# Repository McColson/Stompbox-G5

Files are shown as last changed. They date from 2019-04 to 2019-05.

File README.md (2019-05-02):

# Stompbox-G5
Guitar preamp stompbox

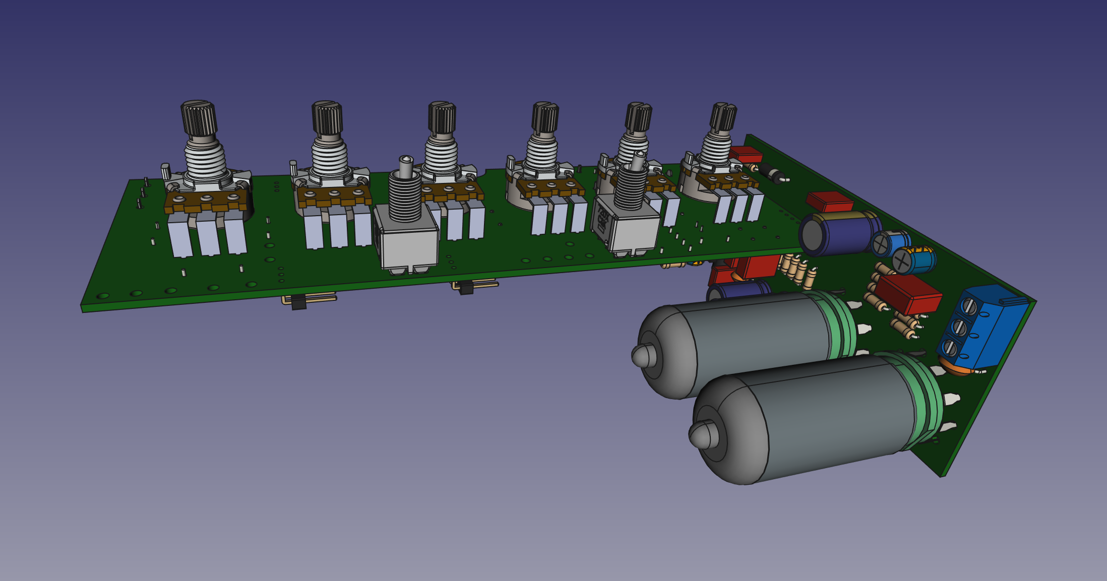
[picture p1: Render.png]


<br />Ce(tte) œuvre est mise à disposition selon les termes de la <a rel="license" href="http://creativecommons.org/licenses/by-nc-sa/4.0/">Licence Creative Commons Attribution - Pas d’Utilisation Commerciale - Partage dans les Mêmes Conditions 4.0 International</a>.

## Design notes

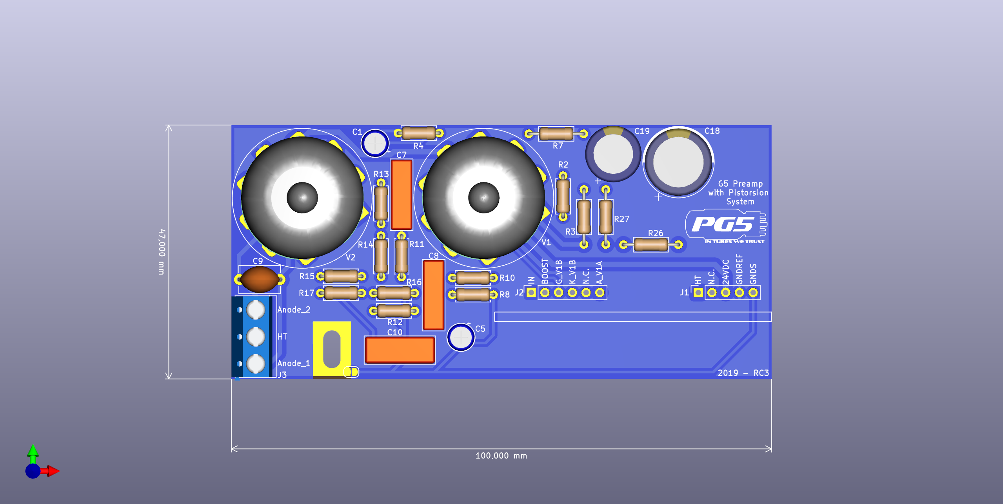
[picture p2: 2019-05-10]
G5_preamp/RC3/PCB_tube/pcb_tube.png

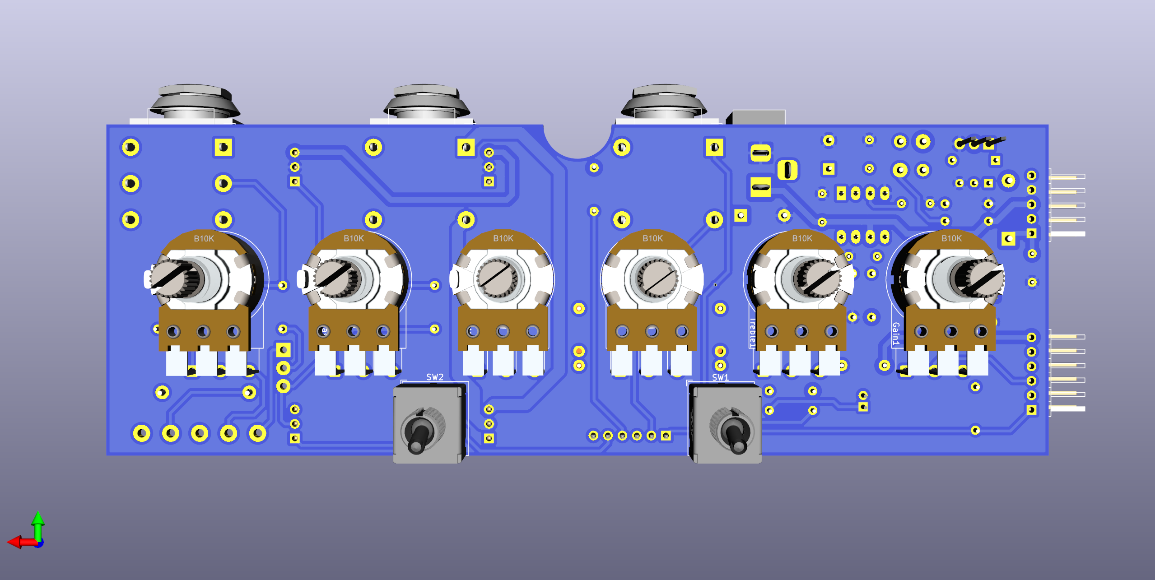
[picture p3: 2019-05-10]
G5_preamp/RC3/PCB_main/pcb_main_2.png

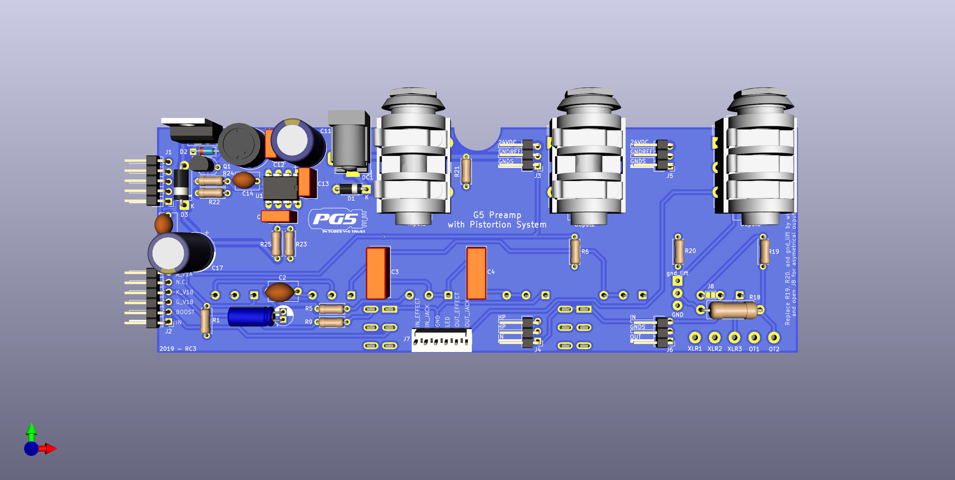
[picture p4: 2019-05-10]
G5_preamp/RC3/PCB_main/pcb_main_1.png

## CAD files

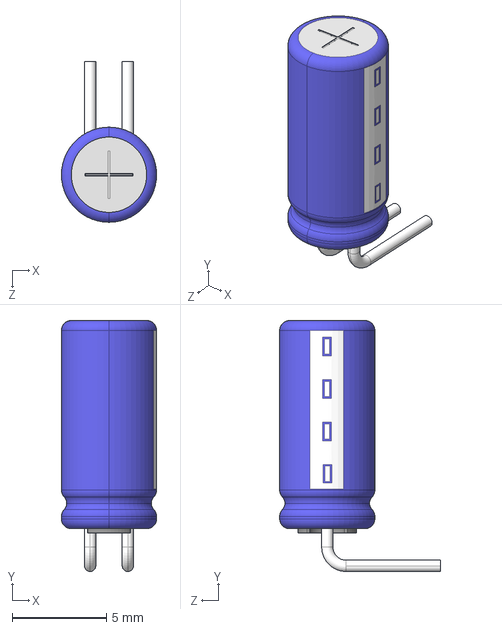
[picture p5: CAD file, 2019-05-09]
G5_preamp/RC3/PCB_main/3D/User Library-Cap electro 5x11x2mm RA.step
5.05 x 13.3 x 8.53 mm

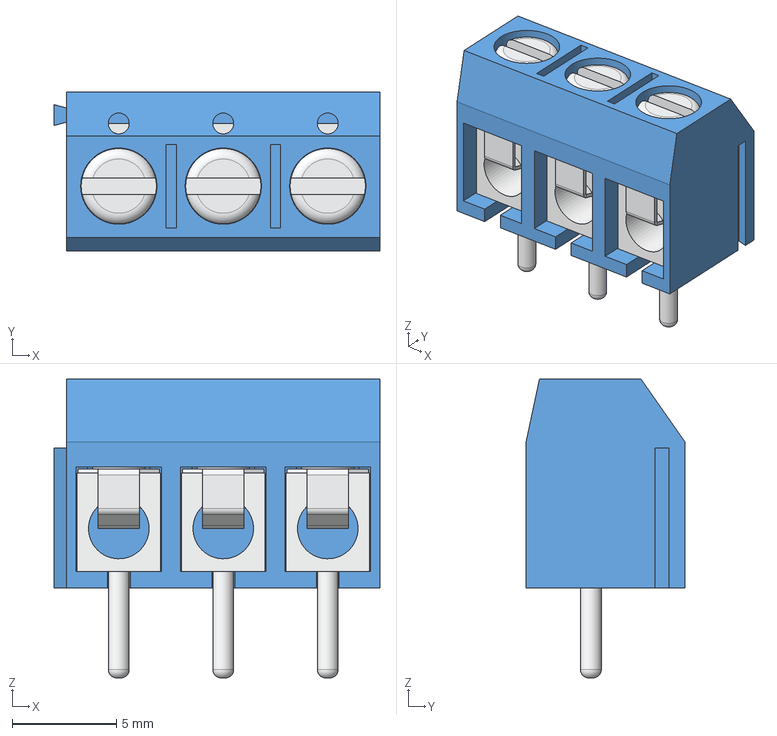
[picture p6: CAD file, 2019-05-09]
G5_preamp/RC3/PCB_tube/3D/DG301-5.0-03.stp
15.6 x 7.60 x 14.3 mm

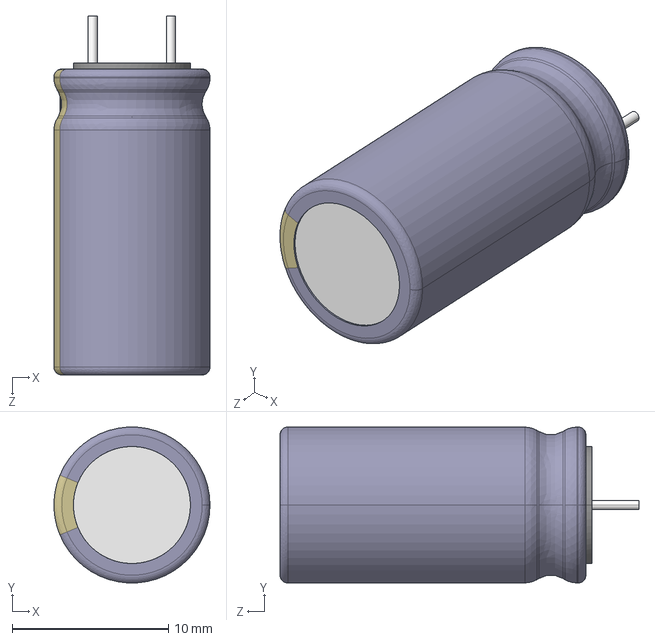
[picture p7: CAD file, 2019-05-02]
G5_preamp/RC3/PCB_main/3D/User Library-CapAluRadial_D100H200P50.step
9.99 x 9.99 x 23.0 mm

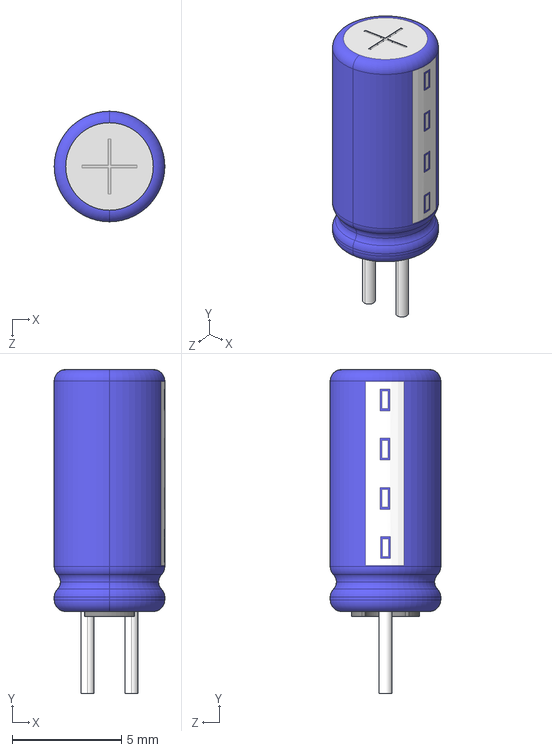
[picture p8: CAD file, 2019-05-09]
G5_preamp/RC3/PCB_tube/3D/User Library-Cap electro 5x11x2mm.step
5.05 x 14.8 x 5.05 mm

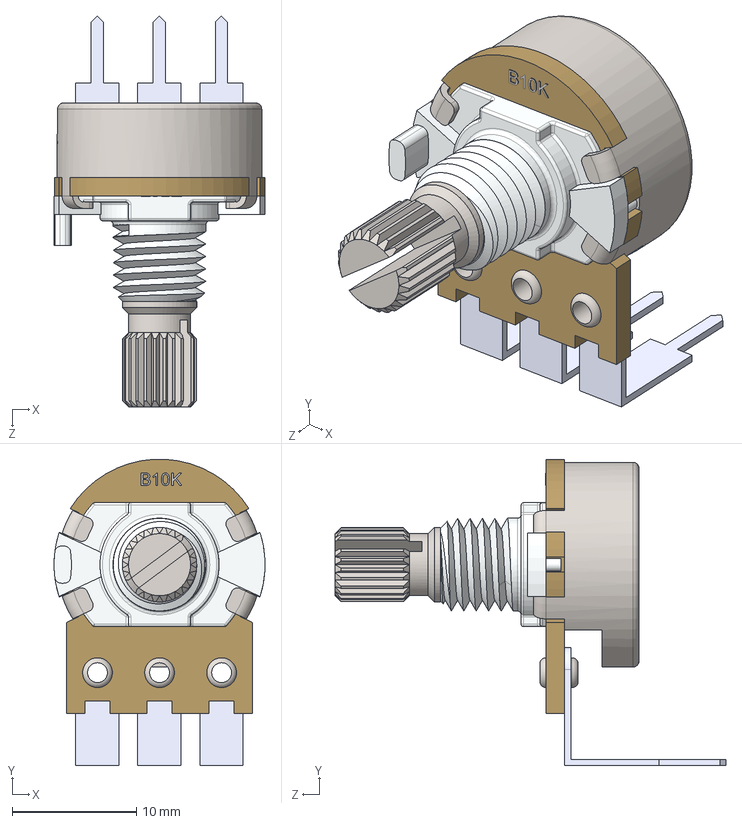
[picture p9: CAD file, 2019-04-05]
G5_preamp/RC3/PCB_main/3D/alpha_16mm_right angled.STEP
17.0 x 24.7 x 31.5 mm
P160NK___ _________
pin right angle x 3
P160NK

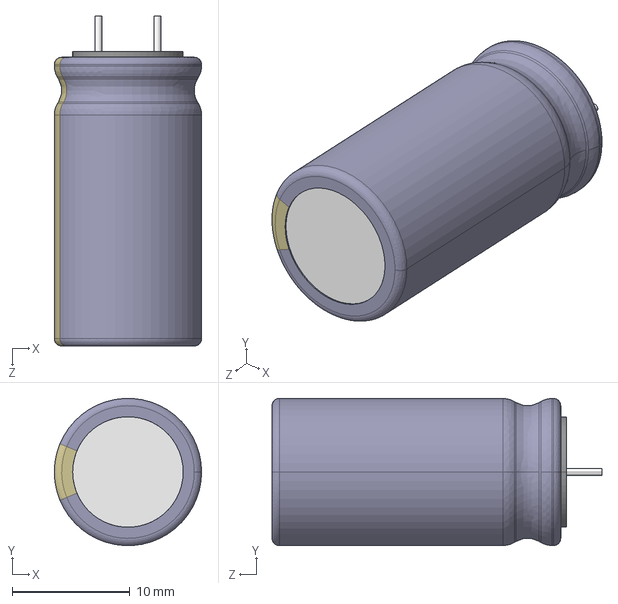
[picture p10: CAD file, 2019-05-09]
G5_preamp/RC3/PCB_tube/3D/User Library-CapAluRadial_D125H250P50.step
12.5 x 12.5 x 28.0 mm

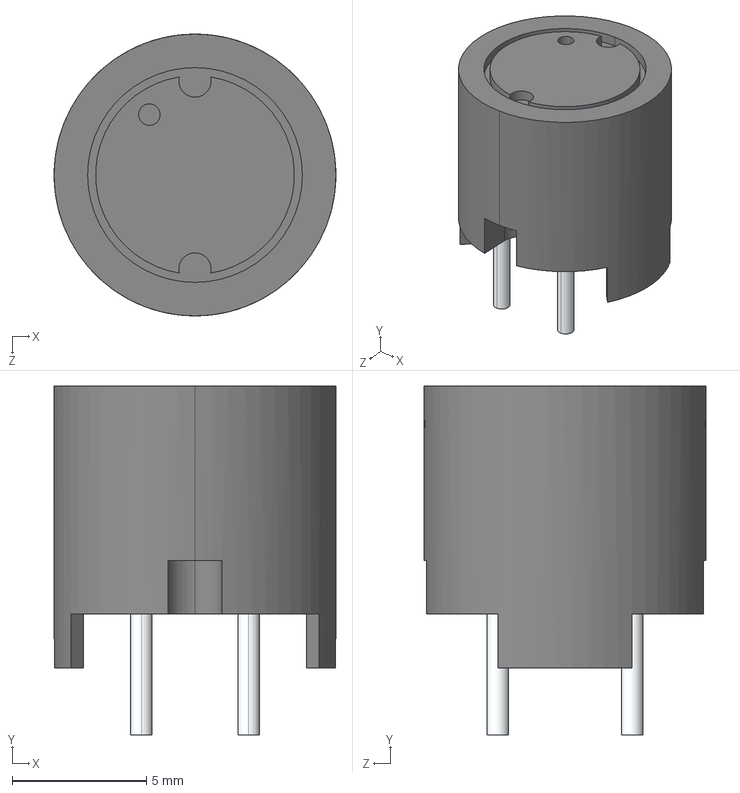
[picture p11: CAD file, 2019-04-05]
G5_preamp/RC3/PCB_main/3D/Murata_1200RS.step
10.5 x 13.0 x 10.5 mm

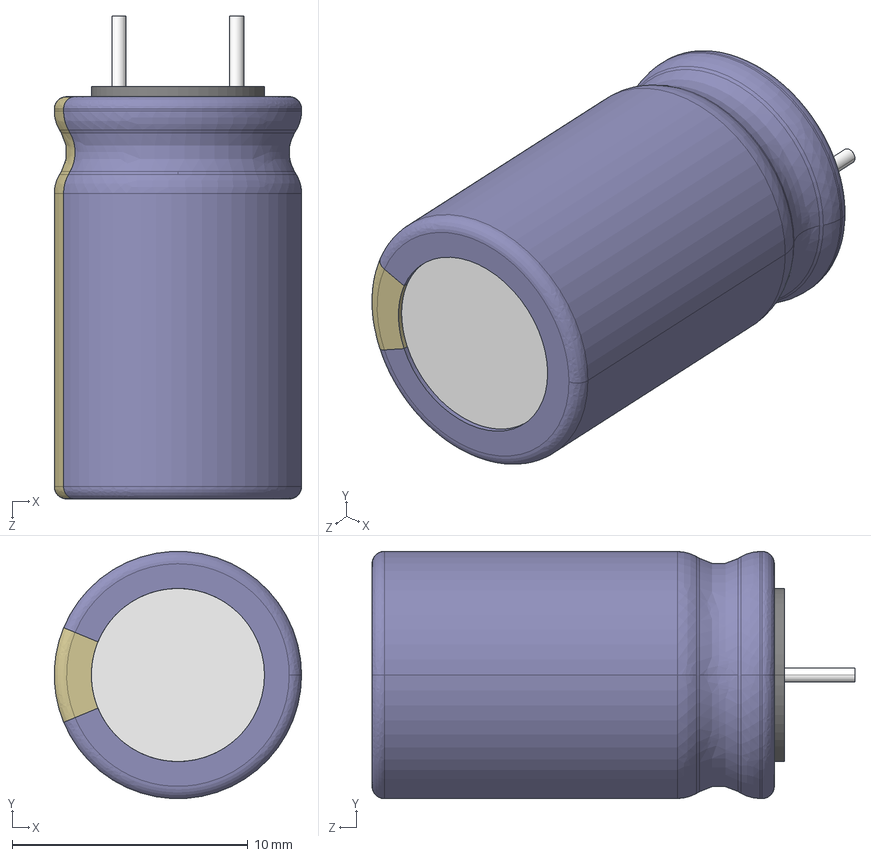
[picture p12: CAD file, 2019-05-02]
G5_preamp/RC3/PCB_tube/3D/User Library-CapAluRadial_D100H160.STEP
10.5 x 10.5 x 20.5 mm
User Library-CapAluRadial_D100H160_rubber_pad
User Library-CapAluRadial_D100H160_can
User Library-CapAluRadial_D100H160_shell_and_minus
User Library-CapAluRadial_D100H160_shell_and_minus_2
User Library-CapAluRadial_D100H160_lead x 2

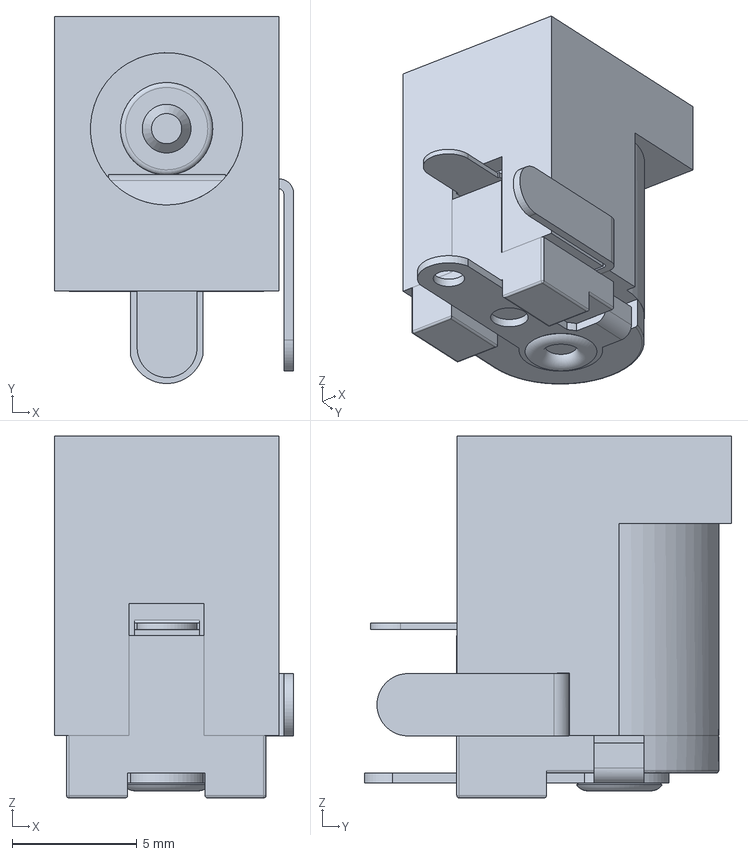
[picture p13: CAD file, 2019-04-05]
G5_preamp/RC3/PCB_main/3D/Lumberg_NEB_21_R.stp
9.59 x 14.7 x 14.5 mm

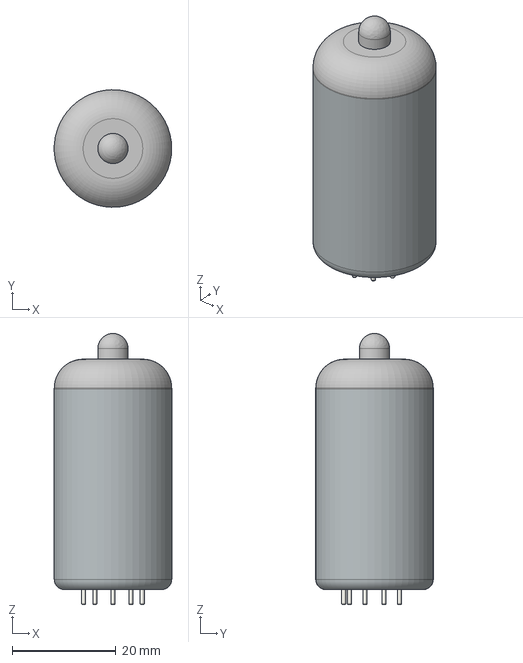
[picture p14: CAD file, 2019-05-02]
G5_preamp/RC3/PCB_tube/3D/Valve_Tube_Noval-B9A.step
22.7 x 22.7 x 52.3 mm

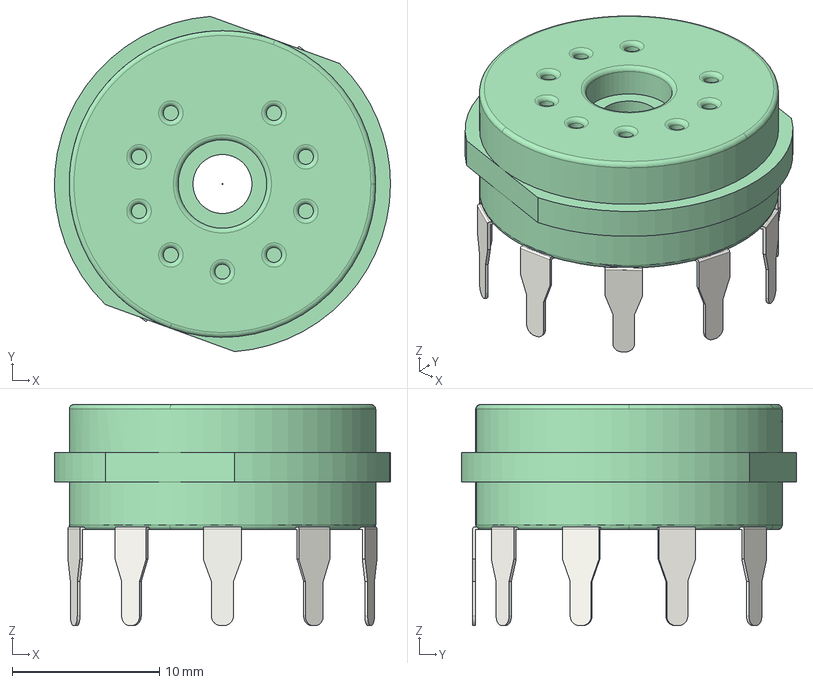
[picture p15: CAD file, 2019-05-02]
G5_preamp/RC3/PCB_tube/3D/Valve_Noval-B9A_Belton-VT9-PT_Socket.step
22.8 x 22.7 x 15.0 mm

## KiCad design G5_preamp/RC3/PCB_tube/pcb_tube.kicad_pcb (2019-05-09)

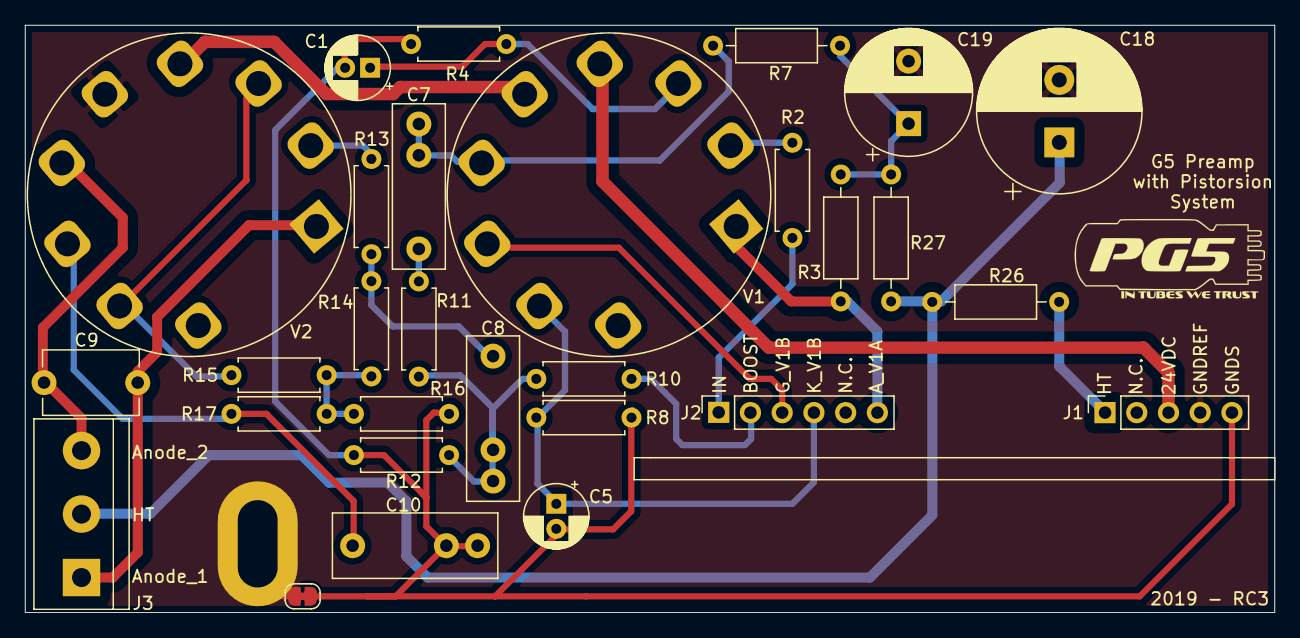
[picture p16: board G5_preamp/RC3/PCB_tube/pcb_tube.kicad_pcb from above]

Board: 2 copper layers, 100.0 x 47.0 mm, 30 parts (0 on the bottom side), 24 nets.

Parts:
C1: 22µF/25v; CP_Radial_D5.0mm_P2.00mm
C5: 1µF/50v; CP_Radial_D5.0mm_P2.00mm
C7, C8: 22nF; C_Rect_L13.0mm_W4.0mm_P10.00mm_FKS3_FKP3_MKS4
C9: 100pF; C_Disc_D7.5mm_W5.0mm_P7.50mm
C10: 100n; C_Rect_L13.0mm_W5.0mm_P10.00mm_FKS3_FKP3_MKS4
C18: 22µF/400v; CP_Radial_D13.0mm_P5.00mm
C19: 10µF/400v; CP_Radial_D10.0mm_P5.00mm
H1: MountingHole_Pad; MountingHole_3.2mm_M3
J1: PSU_TUBE; PinSocket_1x05_P2.54mm_Vertical
J2: PCB_TUBE; PinSocket_1x06_P2.54mm_Vertical
J3: OT; TerminalBlock_bornier-3_P5.08mm
JP1: Jumper; SolderJumper-2_P1.3mm_Bridged_RoundedPad1.0x1.5mm
R2: 33k; R_Axial_DIN0207_L6.3mm_D2.5mm_P7.62mm_Horizontal
R3: 120k; R_Axial_DIN0207_L6.3mm_D2.5mm_P10.16mm_Horizontal
R4, R8: 1.8k; R_Axial_DIN0207_L6.3mm_D2.5mm_P7.62mm_Horizontal
R7: 100k; R_Axial_DIN0207_L6.3mm_D2.5mm_P10.16mm_Horizontal
R10: 100k; R_Axial_DIN0207_L6.3mm_D2.5mm_P7.62mm_Horizontal
R11, R12: 470k; R_Axial_DIN0207_L6.3mm_D2.5mm_P7.62mm_Horizontal
R13: 10k; R_Axial_DIN0207_L6.3mm_D2.5mm_P7.62mm_Horizontal
R14, R17: 1M; R_Axial_DIN0207_L6.3mm_D2.5mm_P7.62mm_Horizontal
R15: 1k; R_Axial_DIN0207_L6.3mm_D2.5mm_P7.62mm_Horizontal
R16: 47k; R_Axial_DIN0207_L6.3mm_D2.5mm_P7.62mm_Horizontal
R26, R27: 1k; R_Axial_DIN0207_L6.3mm_D2.5mm_P10.16mm_Horizontal
V1, V2: ECC83; Valve_Noval-B9A_Belton-VT9-PT_Socket

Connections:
/24VDC: J1.3, V1.4
/A+: C18.1, J3.2, R26.2, R27.1
/A_V1A: J2.6, R3.2, V1.1
/A_V2A: C9.1, J3.3, V2.6
/A_V2B: C9.2, J3.1, V2.1
/BOOST: J2.2, R10.2
/G_V1B: J2.3, V1.7
/HEATER2: V1.5, V2.4
/HT2: J1.1, R26.1
/IN: J2.1, R2.2
/K_V1B: C5.1, J2.4, R8.1, V1.8
GNDREF: C18.2, C19.2, H1.1, J1.4, JP1.1, V2.5
GNDS: C1.2, C5.2, C10.2, C10.3, J1.5, JP1.2, R4.2, R8.2, R12.2, R16.2
unnamed: C1.1, R4.1, V1.3
unnamed: C7.1, R11.1
unnamed: C7.2, R7.2, V1.6
unnamed: C8.1, R13.2, R14.2
unnamed: C8.2, R10.1, R11.2, R12.1
unnamed: C10.1, R17.1, V2.7
unnamed: C19.1, R3.1, R7.1, R27.2
unnamed: R2.1, V1.2
unnamed: R13.1, V2.2
unnamed: R14.1, R15.2, R16.1, R17.2
unnamed: R15.1, V2.3, V2.8

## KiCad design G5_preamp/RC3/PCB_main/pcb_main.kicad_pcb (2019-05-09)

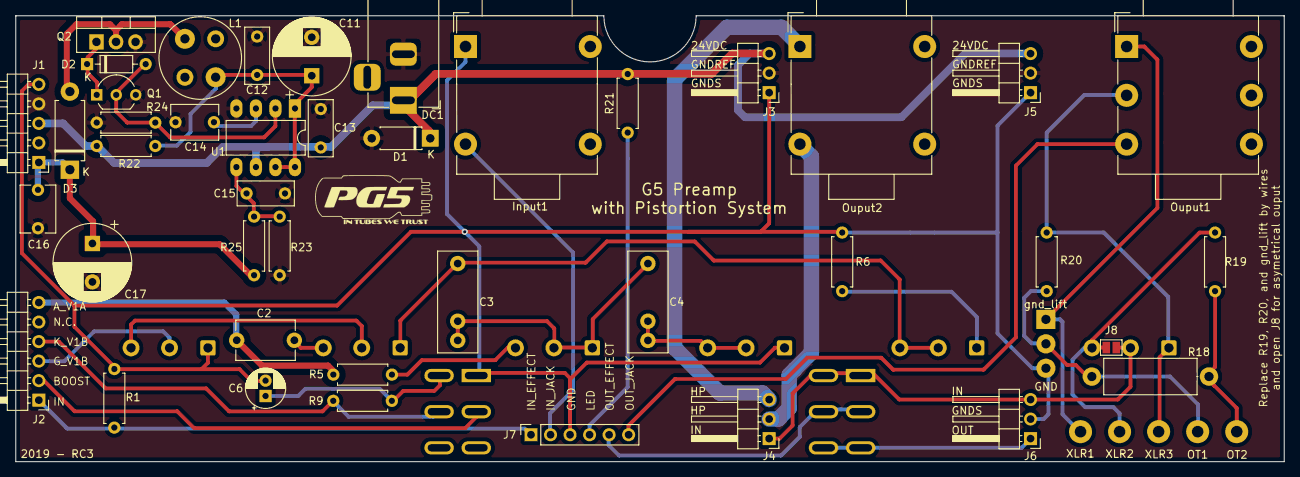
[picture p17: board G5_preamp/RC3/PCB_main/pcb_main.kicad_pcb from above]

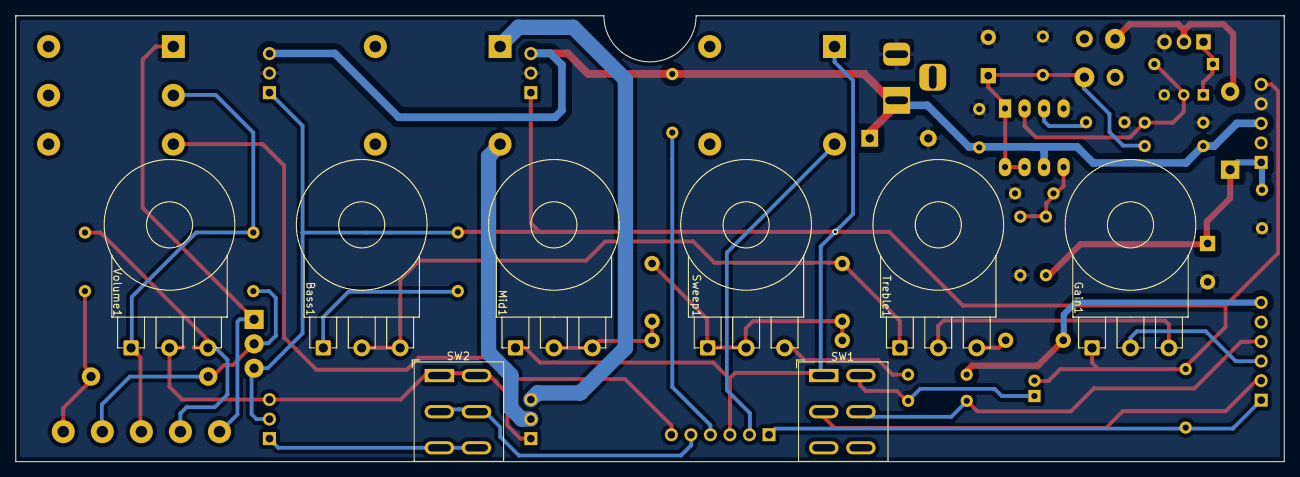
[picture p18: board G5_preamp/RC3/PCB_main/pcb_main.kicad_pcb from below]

Board: 2 copper layers, 165.0 x 58.0 mm, 56 parts (8 on the bottom side), 36 nets.

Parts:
Bass1: 250k log; Potentiometer_Alpha_RV16AF41_Single_Vertical
C2: 250pF; C_Disc_D7.5mm_W5.0mm_P7.50mm
C3: 100nF; C_Rect_L13.0mm_W5.0mm_P7.5mm_or_P10.00mm_FKS3_FKP3_MKS4
C4: 47nF; C_Rect_L13.0mm_W5.0mm_P7.5mm_or_P10.00mm_FKS3_FKP3_MKS4
C6: 22µF/25V; CP_Radial_D5.0mm_P2.00mm
C11: 470µ; CP_Radial_D10.0mm_P5.00mm
C12, C13, C15: 100n; C_Rect_L7.2mm_W3.0mm_P5.00mm_FKS2_FKP2_MKS2_MKP2
C14: 470p; C_Disc_D6.0mm_W4.4mm_P5.00mm
C16: 10n/400V; C_Disc_D6.0mm_W4.4mm_P5.00mm
C17: 4.7µ/400V; CP_Radial_D10.0mm_P5.00mm
D1: 1N4007; D_DO-41_SOD81_P7.62mm_Horizontal
D2: 1N4148; D_DO-35_SOD27_P7.62mm_Horizontal
D3: BYV26; D_DO-15_P10.16mm_Horizontal
DC1: Barrel_Jack; BarrelJack_Horizontal
GND1: GND; SolderWirePad_1x03_P3.175mm_Drill1mm
Gain1: 1M log; Potentiometer_Alpha_RV16AF41_Single_Vertical
Input1: Input; Jack_6.35mm_Neutrik_NMJ4HCD2_Horizontal
J1: PSU_TUBE; PinHeader_1x05_P2.54mm_Horizontal
J2: PCB_TUBE; PinHeader_1x06_P2.54mm_Horizontal
J3: PSU_AMP; PinHeader_1x03_P2.54mm_Horizontal
J4: AMP; PinHeader_1x03_P2.54mm_Horizontal
J5: PSU_SIMCAB; PinHeader_1x03_P2.54mm_Horizontal
J6: SIMCAB; PinHeader_1x03_P2.54mm_Horizontal
J7: 3PDT; PinSocket_1x06_P2.54mm_Vertical
J8: LEVEL 3-2; SolderJumper-2_P1.3mm_Open_Pad1.0x1.5mm
L1: 220µH/1.5A; L_Radial_D10.5mm_P5.00mm_MuRATA_1200RS
Mid1: 100k log; Potentiometer_Alpha_RV16AF41_Single_Vertical
OT1, OT2: 125A; SolderWirePad_1x01_Drill2mm
Ouput1: Out; Jack_3.5mm_Neutrik_NMJ6HCD2_Horizontal
Ouput2: HP; Jack_6.35mm_Neutrik_NMJ4HCD2_Horizontal
Q1: MPS751; TO-92_Inline_Wide
Q2: IRF740; TO-220-3_Vertical
R1: 1M; R_Axial_DIN0207_L6.3mm_D2.5mm_P7.62mm_Horizontal
R5: 47k; R_Axial_DIN0207_L6.3mm_D2.5mm_P7.62mm_Horizontal
R6: 15k; R_Axial_DIN0207_L6.3mm_D2.5mm_P7.62mm_Horizontal
R9, R21: 100k; R_Axial_DIN0207_L6.3mm_D2.5mm_P7.62mm_Horizontal
R18: 100R/2W; R_Axial_DIN0414_L11.9mm_D4.5mm_P15.24mm_Horizontal
R19, R20: 330R; R_Axial_DIN0207_L6.3mm_D2.5mm_P7.62mm_Horizontal
R22: 0.22R; R_Axial_DIN0207_L6.3mm_D2.5mm_P7.62mm_Horizontal
R23: 1.8k; R_Axial_DIN0207_L6.3mm_D2.5mm_P7.62mm_Horizontal
R24: 1k; R_Axial_DIN0207_L6.3mm_D2.5mm_P7.62mm_Horizontal
R25: 430k; R_Axial_DIN0207_L6.3mm_D2.5mm_P7.62mm_Horizontal
SW1: Boost; SW_CK_Lever_DPDT_72xx
SW2: SIMCAB; SW_CK_Lever_DPDT_72xx
Sweep1: 50k lin; Potentiometer_Alpha_RV16AF41_Single_Vertical
Treble1: 250k lin; Potentiometer_Alpha_RV16AF41_Single_Vertical
U1: MC34063AP; DIP-8_W7.62mm_LongPads
Volume1: 1k; Potentiometer_Alpha_RV16AF41_Single_Vertical
XLR1: 1; SolderWirePad_1x01_Drill2mm
XLR2: 2; SolderWirePad_1x01_Drill2mm
XLR3: 3; SolderWirePad_1x01_Drill2mm

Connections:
+24V: C13.1, D1.1, DC1.1, J1.3, J3.3, J5.3, R21.2, R22.1, U1.6
/A_V1A: C2.2, J2.6, R5.1
/BOOST: J2.2, SW1.2
/G_V1B: Gain1.2, J2.3
/HP1: J4.2, Ouput2.T
/HP2: J4.3, Ouput2.S
/HT1: D3.2, L1.2, Q2.2
/HT2: C16.1, C17.1, D3.1, J1.1, R25.1
/IN_EFFECT: J2.1, J7.1, R1.1
/IN_JACK: Input1.T, J7.2
/K_V1B: J2.4, R9.1, SW1.5
/LED: J7.4, R21.1
/LINE_OUT: J4.1, J6.3, J8.2, SW2.1, SW2.4, Volume1.2
/OUT_EFFECT: J7.5, SW2.2, SW2.5
/OUT_JACK: J7.6, Ouput1.T
/PEAK: C11.1, C12.1, L1.1, R22.2, U1.1, U1.7, U1.8
/SIMCAB_OUT: J6.1, SW2.3, SW2.6
GNDREF: C11.2, C12.2, C13.2, C14.2, C15.2, C16.2, C17.2, D1.2, DC1.2, J1.4, J3.2, J5.2, Q1.3, Q2.3, R23.2, R24.2, U1.4
GNDS: C6.2, GND1.3, Gain1.1, Input1.S, J1.5, J3.1, J5.1, J6.2, J7.3, Mid1.1, R1.2, R6.2, SW1.1
unnamed: Bass1.1, R6.1
unnamed: Bass1.2, Bass1.3, C3.1, Treble1.1
unnamed: C2.1, Treble1.3
unnamed: C3.2, C4.1, Sweep1.1, Sweep1.2
unnamed: C4.2, Mid1.2, Mid1.3
unnamed: C6.1, R9.2, SW1.4
unnamed: C14.1, U1.3
unnamed: C15.1, R23.1, R25.2, U1.5
unnamed: D2.1, Q1.1, Q2.1
unnamed: D2.2, Q1.2, R24.1, U1.2
unnamed: GND1.1, Ouput1.S, XLR1.1
unnamed: GND1.2, OT1.1, R18.2, R20.2
unnamed: Gain1.3, Treble1.2
unnamed: J8.1, R19.1, Volume1.3, XLR2.1
unnamed: OT2.1, R18.1, R19.2
unnamed: Ouput1.R, R20.1, Volume1.1, XLR3.1
unnamed: R5.2, Sweep1.3

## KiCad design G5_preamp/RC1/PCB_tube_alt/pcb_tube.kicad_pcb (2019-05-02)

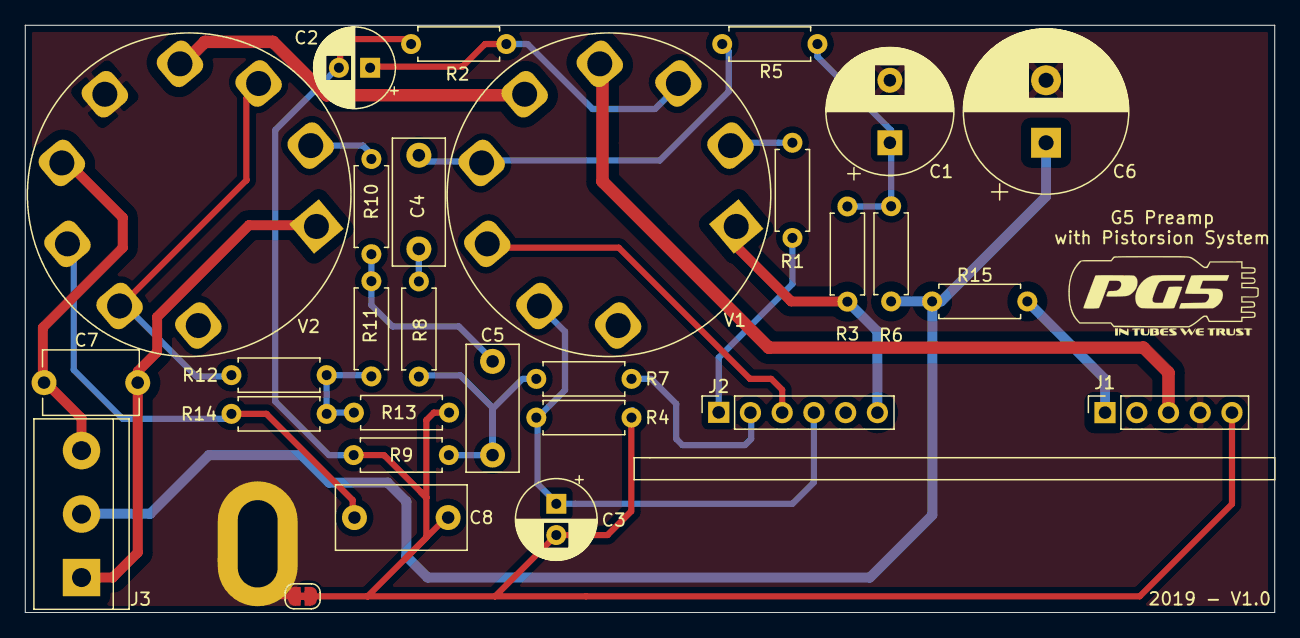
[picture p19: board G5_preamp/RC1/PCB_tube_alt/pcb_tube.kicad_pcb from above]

Board: 2 copper layers, 100.0 x 47.0 mm, 29 parts (0 on the bottom side), 24 nets.

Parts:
C1: 10µF/350v; CP_Radial_D10.0mm_P5.00mm
C2: 22µF/25v; CP_Radial_D6.3mm_P2.50mm
C3: 1µF/25v; CP_Radial_D6.3mm_P2.50mm
C4, C5: 22nF; C_Rect_L10.0mm_W4.0mm_P7.50mm_MKS4
C6: 22µF/350v; CP_Radial_D13.0mm_P5.00mm
C7: 100pF; C_Disc_D7.5mm_W5.0mm_P7.50mm
C8: 100n; C_Rect_L10.3mm_W5.0mm_P7.50mm_MKS4
J1: PSU_TUBE; PinSocket_1x05_P2.54mm_Vertical
J2: PCB_TUBE; PinSocket_1x06_P2.54mm_Vertical
J3: OT; TerminalBlock_bornier-3_P5.08mm
JP1: Jumper; SolderJumper-2_P1.3mm_Bridged_RoundedPad1.0x1.5mm
R1: 33k; R_Axial_DIN0207_L6.3mm_D2.5mm_P7.62mm_Horizontal
R2, R4: 1.8k; R_Axial_DIN0207_L6.3mm_D2.5mm_P7.62mm_Horizontal
R3: 120k; R_Axial_DIN0207_L6.3mm_D2.5mm_P7.62mm_Horizontal
R5, R7: 100k; R_Axial_DIN0207_L6.3mm_D2.5mm_P7.62mm_Horizontal
R6, R12, R15: 1k; R_Axial_DIN0207_L6.3mm_D2.5mm_P7.62mm_Horizontal
R8, R9: 470k; R_Axial_DIN0207_L6.3mm_D2.5mm_P7.62mm_Horizontal
R10: 10k; R_Axial_DIN0207_L6.3mm_D2.5mm_P7.62mm_Horizontal
R11, R14: 1M; R_Axial_DIN0207_L6.3mm_D2.5mm_P7.62mm_Horizontal
R13: 47k; R_Axial_DIN0207_L6.3mm_D2.5mm_P7.62mm_Horizontal
V1, V2: ECC83; Valve_Noval-B9A_Belton-VT9-PT_Socket

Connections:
/24VDC: J1.3, V1.4
/A+: C6.1, J3.2, R6.1, R15.2
/A_V1A: J2.6, R3.2, V1.1
/A_V2A: C7.1, J3.3, V2.6
/A_V2B: C7.2, J3.1, V2.1
/BOOST: J2.2, R7.2
/G_V1B: J2.3, V1.7
/HEATER2: V1.5, V2.4
/HT2: J1.1, R15.1
/IN: J2.1, R1.2
/K_V1B: C3.1, J2.4, R4.1, V1.8
GNDREF: C1.2, C6.2, J1.4, JP1.1, V2.5
GNDS: C2.2, C3.2, C8.2, J1.5, JP1.2, R2.2, R4.2, R9.2, R13.2
unnamed: C1.1, R3.1, R5.1, R6.2
unnamed: C2.1, R2.1, V1.3
unnamed: C4.1, R8.1
unnamed: C4.2, R5.2, V1.6
unnamed: C5.1, R10.2, R11.2
unnamed: C5.2, R7.1, R8.2, R9.1
unnamed: C8.1, R14.1, V2.7
unnamed: R1.1, V1.2
unnamed: R10.1, V2.2
unnamed: R11.1, R12.2, R13.1, R14.2
unnamed: R12.1, V2.3, V2.8

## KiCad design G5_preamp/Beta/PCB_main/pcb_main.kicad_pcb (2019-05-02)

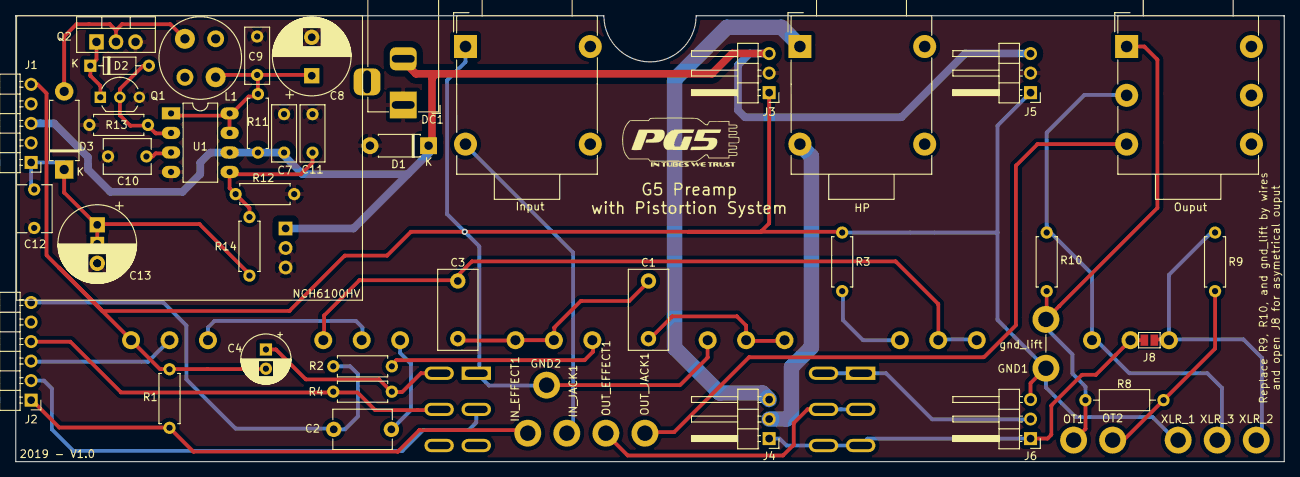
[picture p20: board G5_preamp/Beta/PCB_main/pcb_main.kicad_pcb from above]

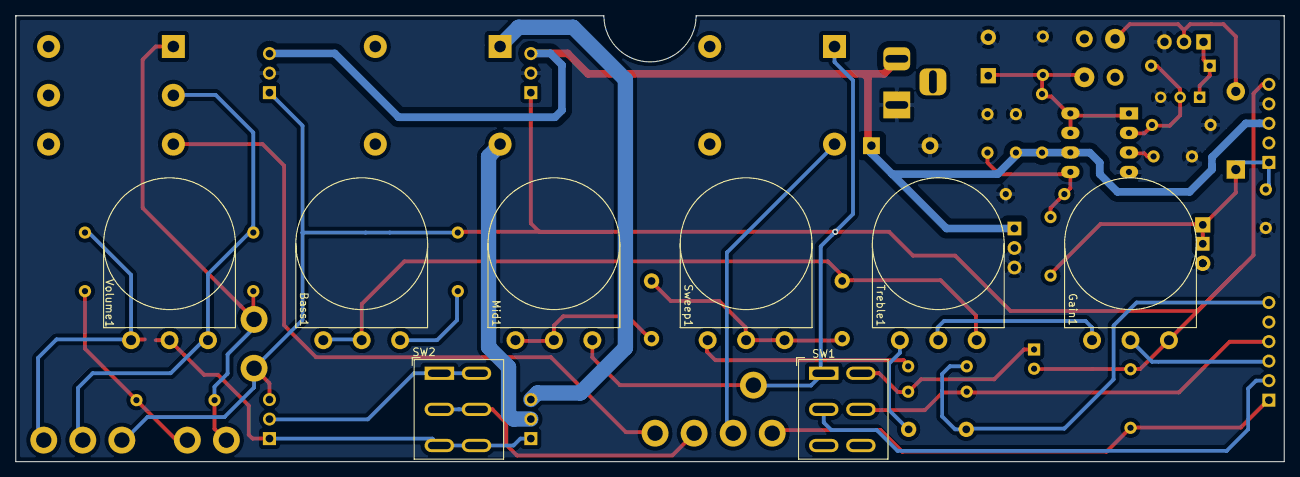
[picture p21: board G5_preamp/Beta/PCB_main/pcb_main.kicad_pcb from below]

Board: 2 copper layers, 165.0 x 58.0 mm, 60 parts (8 on the bottom side), 34 nets.

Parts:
Bass1: 250k log; Potentiometer_Omeg_PC16BU_Vertical
C1: 47nF; C_Rect_L10.3mm_W5.0mm_P7.50mm_MKS4
C2: 250pF; C_Disc_D7.5mm_W5.0mm_P7.50mm
C3: 100nF; C_Rect_L10.3mm_W5.0mm_P7.50mm_MKS4
C4: 22µF/35V; CP_Radial_D6.3mm_P2.50mm
C7, C9, C11: 100n; C_Rect_L7.2mm_W3.0mm_P5.00mm_FKS2_FKP2_MKS2_MKP2
C8: 470µ; CP_Radial_D10.0mm_P5.00mm
C10: 470p; C_Disc_D6.0mm_W4.4mm_P5.00mm
C12: 10n/400V; C_Disc_D6.0mm_W4.4mm_P5.00mm
C13: 4.7µ/350V; CP_Radial_D10.0mm_P5.00mm
D1: 1N4007; D_DO-41_SOD81_P7.62mm_Horizontal
D2: 1N4148; D_DO-35_SOD27_P7.62mm_Horizontal
D3: BYV26; D_DO-15_P10.16mm_Horizontal
DC1: Barrel_Jack; BarrelJack_Horizontal
GND1: GND; SolderWirePad_1x02_P7.62mm_Drill2mm
GND2: MASSE; SolderWirePad_1x01_Drill2mm
Gain1: 1M log; Potentiometer_Omeg_PC16BU_Vertical
HP: HP; Jack_6.35mm_Neutrik_NMJ4HCD2_Horizontal
IN_EFFECT1: IN_EFFECT; SolderWirePad_1x01_Drill2mm
IN_JACK1: IN_JACK; SolderWirePad_1x01_Drill2mm
Input: Input; Jack_6.35mm_Neutrik_NMJ4HCD2_Horizontal
J1: PSU_TUBE; PinHeader_1x05_P2.54mm_Horizontal
J2: PCB_TUBE; PinHeader_1x06_P2.54mm_Horizontal
J3: PSU_AMP; PinHeader_1x03_P2.54mm_Horizontal
J4: AMP; PinHeader_1x03_P2.54mm_Horizontal
J5: PSU_SIMCAB; PinHeader_1x03_P2.54mm_Horizontal
J6: SIMCAB; PinHeader_1x03_P2.54mm_Horizontal
J8: LEVEL 3-2; SolderJumper-2_P1.3mm_Open_Pad1.0x1.5mm
L1: 220µH/1.5A; L_Radial_D10.5mm_P5.00mm_MuRATA_1200RS
Mid1: 100k log; Potentiometer_Omeg_PC16BU_Vertical
NCH6100HV: NCH6100HV
OT1, OT2: 125A; SolderWirePad_1x01_Drill2mm
OUT_EFFECT1: 1; SolderWirePad_1x01_Drill2mm
OUT_JACK1: 1; SolderWirePad_1x01_Drill2mm
Ouput: Out; Jack_3.5mm_Neutrik_NMJ6HCD2_Horizontal
Q1: MPS751; TO-92_Inline_Wide
Q2: IRF740; TO-220-3_Vertical
R1: 1M; R_Axial_DIN0207_L6.3mm_D2.5mm_P7.62mm_Horizontal
R2: 47k; R_Axial_DIN0207_L6.3mm_D2.5mm_P7.62mm_Horizontal
R3: 15k; R_Axial_DIN0207_L6.3mm_D2.5mm_P7.62mm_Horizontal
R4: 100k; R_Axial_DIN0207_L6.3mm_D2.5mm_P7.62mm_Horizontal
R8: 100R/2W; R_Axial_DIN0207_L6.3mm_D2.5mm_P10.16mm_Horizontal
R9, R10: 330R; R_Axial_DIN0207_L6.3mm_D2.5mm_P7.62mm_Horizontal
R11: 0.22R; R_Axial_DIN0207_L6.3mm_D2.5mm_P7.62mm_Horizontal
R12: 1.8k; R_Axial_DIN0207_L6.3mm_D2.5mm_P7.62mm_Horizontal
R13: 1k; R_Axial_DIN0207_L6.3mm_D2.5mm_P7.62mm_Horizontal
R14: 430k; R_Axial_DIN0207_L6.3mm_D2.5mm_P7.62mm_Horizontal
SW1: Boost; SW_CK_Lever_DPDT_72xx
SW2: SIMCAB; SW_CK_Lever_DPDT_72xx
Sweep1: 50k lin; Potentiometer_Omeg_PC16BU_Vertical
Treble1: 250k lin; Potentiometer_Omeg_PC16BU_Vertical
U1: MC34063AP; DIP-8_W7.62mm_LongPads
Volume1: 1k; Potentiometer_Omeg_PC16BU_Vertical
XLR_1: 1; SolderWirePad_1x01_Drill2mm
XLR_2: 2; SolderWirePad_1x01_Drill2mm
XLR_3: 3; SolderWirePad_1x01_Drill2mm

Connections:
+24V: C7.1, D1.1, DC1.2, J1.3, J3.3, J5.3, NCH6100HV.1, R11.1, U1.6
/A_V1A: C2.2, J2.6, R2.1
/BOOST: J2.2, SW1.2
/G_V1B: Gain1.2, J2.3
/HP1: HP.T, J4.2
/HP2: HP.S, J4.3
/HT1: D3.2, L1.2, Q2.2
/HT2: C12.1, C13.1, D3.1, J1.1, NCH6100HV.4, R14.1
/IN_EFFECT: IN_EFFECT1.1, J2.1, R1.1
/K_V1B: J2.4, R4.1, SW1.5
/LINE_OUT: J4.1, J6.1, J8.2, SW2.3, SW2.6, Volume1.2
/PEAK: C8.1, C9.1, L1.1, R11.2, U1.1, U1.7, U1.8
/SIMCAB_OUT: J6.2, SW2.1, SW2.4
GNDREF: C7.2, C8.2, C9.2, C10.2, C11.2, C12.2, C13.2, D1.2, DC1.1, J1.4, J3.2, J5.2, NCH6100HV.2, NCH6100HV.3, NCH6100HV.5, Q1.3, Q2.3, R12.2, R13.2, U1.4
GNDS: C4.2, GND1.2, GND2.1, Gain1.1, Input.S, J1.5, J3.1, J5.1, J6.3, Mid1.1, R1.2, R3.2, SW1.1, XLR_1.1
unnamed: Bass1.1, R3.1
unnamed: Bass1.2, Bass1.3, C3.1, Treble1.1
unnamed: C1.1, C3.2, Sweep1.1, Sweep1.2
unnamed: C1.2, Mid1.2, Mid1.3
unnamed: C2.1, Treble1.3
unnamed: C4.1, R4.2, SW1.4
unnamed: C10.1, U1.3
unnamed: C11.1, R12.1, R14.2, U1.5
unnamed: D2.1, Q1.1, Q2.1
unnamed: D2.2, Q1.2, R13.1, U1.2
unnamed: GND1.1, OT1.1, Ouput.S, R8.2, R10.2
unnamed: Gain1.3, Treble1.2
unnamed: IN_JACK1.1, Input.T
unnamed: J8.1, R9.1, Volume1.3, XLR_2.1
unnamed: OT2.1, R8.1, R9.2
unnamed: OUT_EFFECT1.1, SW2.2, SW2.5
unnamed: OUT_JACK1.1, Ouput.T
unnamed: Ouput.R, R10.1, Volume1.1, XLR_3.1
unnamed: R2.2, Sweep1.3

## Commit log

2019-04-05 Rename
    rename to G5_preamp
    [Lumberg_NEB_21_R.stp, Murata_1200RS.step, alpha_16mm_right angled.STEP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]
2019-04-19 DC-DC move
    DC-DC Converter move from PCB_tube to PCB_main
    [User Library-CapAluRadial_D100H160.STEP, User Library-CapAluRadial_D100H200P50.step, Valve_Noval-B9A_Belton-VT9-PT_Socket.step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]
2019-04-19 Gerber export
    Last MAJ with GERBER
    [Valve_Tube_Noval-B9A_1).step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]
2019-04-21 RC1
    Release Candidate 1
    [Lumberg_NEB_21_R.stp, Murata_1200RS.step, User Library-CapAluRadial_D100H160.STEP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]
2019-04-22 Validation RC1
    Commande PCB
    [pcb_main.kicad_pcb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]
2019-04-23 Licence CC
    Information licence CC on schematic and pcb files
    [pcb_main.kicad_pcb, pcb_main.sch, pcb_tube.kicad_pcb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]
2019-04-25 RC2
    Release Candidate 2
    [Lumberg_NEB_21_R.stp, Murata_1200RS.step, User Library-CapAluRadial_D100H160.STEP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]
2019-04-26 BOM adjustement
    [BOM.ods, pcb_main.sch]
2019-04-28 DC jack Polarity change
    DC Jack polarity change and some capacitor footprint mod
    [BOM.ods, pcb_main.kicad_pcb, pcb_main.sch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]
2019-04-29 Reverse SimulHP switch
    [pcb_main.kicad_pcb, pcb_main.sch]
2019-05-02 3D setting
    [Lumberg_NEB_21_R.stp, Murata_1200RS.step, User Library-CapAluRadial_D100H160.STEP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]
2019-05-02 Update G5_preamp.pdf
    New Schematic annotation
2019-05-05 GND lift arrangement
    GND lift arrangement
    [pcb_main.kicad_pcb, pcb_main.sch]
2019-05-07 Pad fixation pcb_tube
    [pcb_tube.kicad_pcb]
2019-05-07 mod pcb_tube
    [pcb_tube.kicad_pcb, pcb_tube.sch]
2019-05-08 Schematic G5_preamp
2019-05-09 RC3 Update
    [Lumberg_NEB_21_R.stp, Murata_1200RS.step, User Library-CapAluRadial_D100H160.STEP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]
2019-05-09 RC3 update
    Cathode Cap change 3d models and place (pcb-main)
    [DG301-5.0-03.stp, User Library-Cap electro 5x11x2mm RA.step, User Library-Cap electro 5x11x2mm.step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]

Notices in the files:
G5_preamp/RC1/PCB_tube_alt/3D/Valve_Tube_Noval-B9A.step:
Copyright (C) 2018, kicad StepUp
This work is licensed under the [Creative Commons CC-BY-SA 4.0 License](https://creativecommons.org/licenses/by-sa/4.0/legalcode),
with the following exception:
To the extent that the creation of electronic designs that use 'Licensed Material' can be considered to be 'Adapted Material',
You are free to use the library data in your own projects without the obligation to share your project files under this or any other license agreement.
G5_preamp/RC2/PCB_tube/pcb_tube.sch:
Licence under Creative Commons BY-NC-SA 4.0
